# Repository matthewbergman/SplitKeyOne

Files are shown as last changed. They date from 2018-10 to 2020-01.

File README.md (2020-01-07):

# SplitKeyOne
Very simple split keyboard PCB layout and firmware using Cherry MX switches and Teensy3 micro.

### CAD
KiCAD pcb files

TODO:
* Fix the stabalizer mounting holes for vertically mounted keycaps
* Add more mounting holes for rigidity
* Switch to SMT diodes or switches with built in diodes

### SplitKeyOneFirmware
Simple firmware to read the key matrix and send the correct keypress or keyrelease signal. Optionally lights up the LED for each key while it is pressed.

TODO:
* Emulate mouse buttons
* Emulate joystick axis and buttons

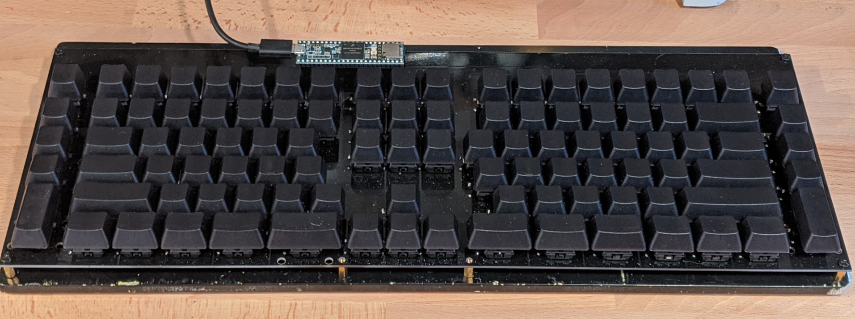
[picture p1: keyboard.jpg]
Keyboard


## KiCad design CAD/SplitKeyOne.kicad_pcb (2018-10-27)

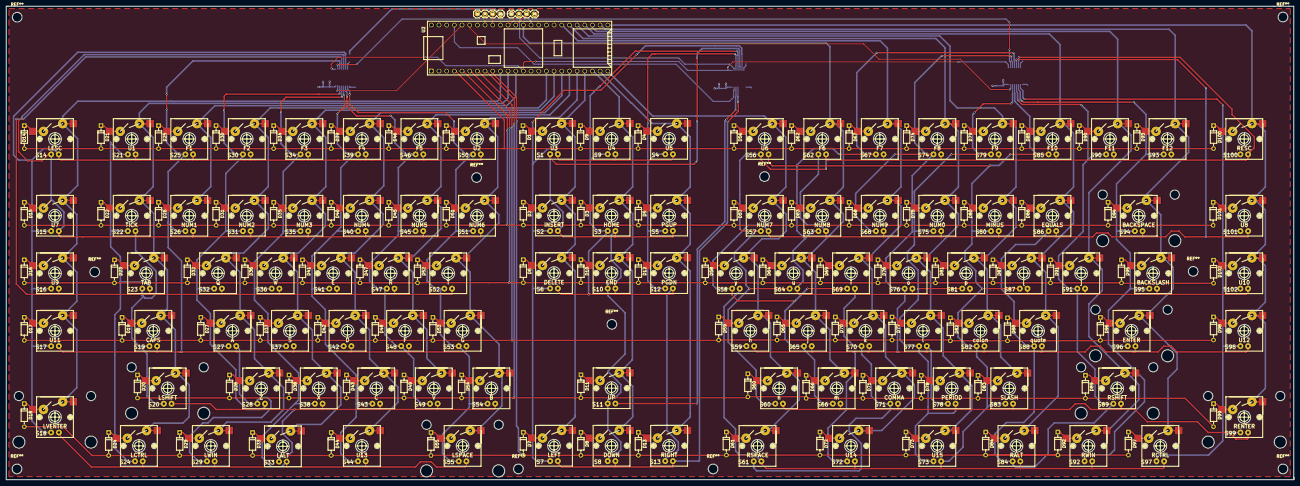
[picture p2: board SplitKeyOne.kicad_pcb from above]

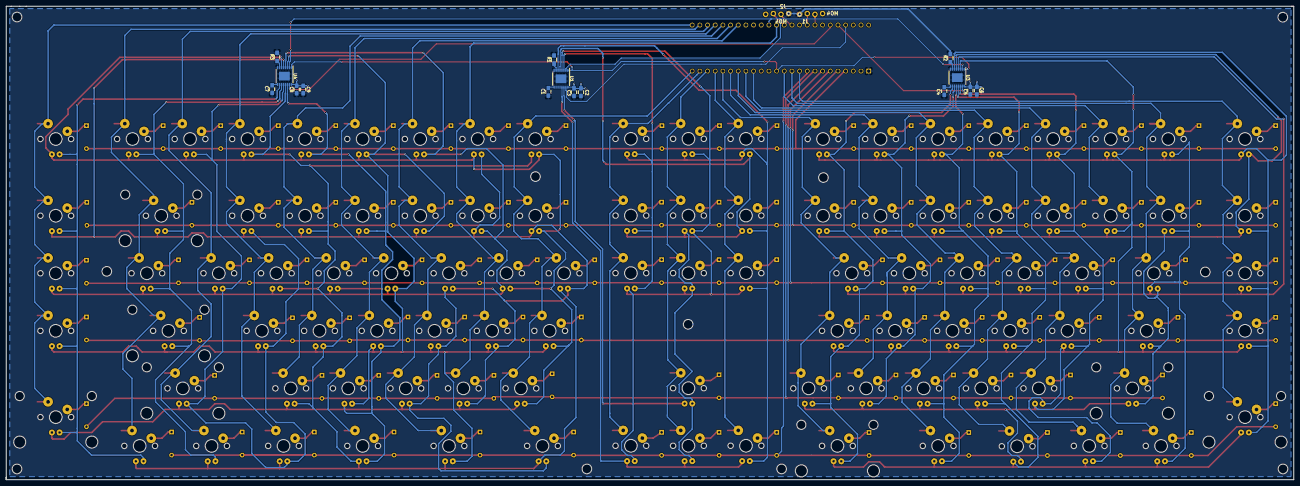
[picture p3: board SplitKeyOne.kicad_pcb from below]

Board: 2 copper layers, 426.2 x 156.7 mm, 222 parts (15 on the bottom side), 169 nets.

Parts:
C1, C4: 27pF; C_0805_HandSoldering
C2, C5, C8: 22uF; C_0805_HandSoldering
C3, C6, C9: 0.1uF; C_0805_HandSoldering
C7: C; C_0805_HandSoldering
D1, D2, D3, D4, D5, D6, D7, D8, D9, D10, D11, D12, D13, D14, D15, D16, D17, D18, D19, D20, D21, D22, D23, D24, D25, D26, D27, D28, D29, D30, D31, D32, D33, D34, D35, D36, D37, D38, D39, D40, D41, D42, D43, D44, D45, D46, D47, D48, D49, D50, D51, D52, D53, D54, D55, D56, D57, D58, D59, D60, D61, D62, D63, D64, D65, D66, D67, D68, D69, D70, D71, D72, D73, D74, D75, D76, D77, D78, D79, D80, D81, D82, D83, D84, D85, D86, D87, D88, D89, D90, D91, D92, D93, D94, D95, D96, D97, D98, D99, D100, D101, D102: D; D_DO-35_SOD27_P7.62mm_Horizontal
J1, J2: M04; SparkFun-1X04_LOCK
R1, R3: 56k; R_0805_HandSoldering
R2: 56K; R_0805_HandSoldering
S1: U3; CHERRY-MX-LED-Socket
S2: INSERT; CHERRY-MX-LED-Socket
S3: HOME; CHERRY-MX-LED-Socket
S4: U5; CHERRY-MX-LED-Socket
S5: PGUP; CHERRY-MX-LED-Socket
S6: DELETE; CHERRY-MX-LED-Socket
S7: LEFT; CHERRY-MX-LED-Socket
S8: DOWN; CHERRY-MX-LED-Socket
S9: U4; CHERRY-MX-LED-Socket
S10: END; CHERRY-MX-LED-Socket
S11: UP; CHERRY-MX-LED-Socket
S12: PGDN; CHERRY-MX-LED-Socket
S13: RIGHT; CHERRY-MX-LED-Socket
S14: LESC; CHERRY-MX-LED-Socket
S15: U7; CHERRY-MX-LED-Socket
S16: U9; CHERRY-MX-LED-Socket
S17: U11; CHERRY-MX-LED-Socket
S18: LVENTER; CHERRY-MX-LED-Socket-2-stabilizer
S19: CAPS; CHERRY-MX-LED-Socket
S20: LSHIFT; CHERRY-MX-LED-Socket-2-stabilizer
S21: U1; CHERRY-MX-LED-Socket
S22: TICK; CHERRY-MX-LED-Socket
S23: TAB; CHERRY-MX-LED-Socket
S24: LCTRL; CHERRY-MX-LED-Socket
S25: F1; CHERRY-MX-LED-Socket
S26: NUM1; CHERRY-MX-LED-Socket
S27: A; CHERRY-MX-LED-Socket
S28: Z; CHERRY-MX-LED-Socket
S29: LWIN; CHERRY-MX-LED-Socket
S30: F2; CHERRY-MX-LED-Socket
S31: NUM2; CHERRY-MX-LED-Socket
S32: Q; CHERRY-MX-LED-Socket
S33: LALT; CHERRY-MX-LED-Socket
S34: F3; CHERRY-MX-LED-Socket
S35: NUM3; CHERRY-MX-LED-Socket
S36: W; CHERRY-MX-LED-Socket
S37: S; CHERRY-MX-LED-Socket
S38: X; CHERRY-MX-LED-Socket
S39: F4; CHERRY-MX-LED-Socket
S40: NUM4; CHERRY-MX-LED-Socket
S41: E; CHERRY-MX-LED-Socket
S42: D; CHERRY-MX-LED-Socket
S43: C; CHERRY-MX-LED-Socket
S44: U13; CHERRY-MX-LED-Socket
S45: NUM5; CHERRY-MX-LED-Socket
S46: F5; CHERRY-MX-LED-Socket
S47: R; CHERRY-MX-LED-Socket
S48: F; CHERRY-MX-LED-Socket
S49: V; CHERRY-MX-LED-Socket
S50: U2; CHERRY-MX-LED-Socket
S51: NUM6; CHERRY-MX-LED-Socket
S52: T; CHERRY-MX-LED-Socket
S53: G; CHERRY-MX-LED-Socket
S54: B; CHERRY-MX-LED-Socket
S55: LSPACE; CHERRY-MX-LED-Socket-2-stabilizer
S56: U6; CHERRY-MX-LED-Socket
S57: NUM7; CHERRY-MX-LED-Socket
S58: y; CHERRY-MX-LED-Socket
S59: h; CHERRY-MX-LED-Socket
S60: n; CHERRY-MX-LED-Socket
S61: RSPACE; CHERRY-MX-LED-Socket
S62: F6; CHERRY-MX-LED-Socket
S63: NUM8; CHERRY-MX-LED-Socket
S64: u; CHERRY-MX-LED-Socket
S65: j; CHERRY-MX-LED-Socket
S66: m; CHERRY-MX-LED-Socket
S67: F7; CHERRY-MX-LED-Socket
S68: NUM9; CHERRY-MX-LED-Socket
S69: i; CHERRY-MX-LED-Socket
S70: k; CHERRY-MX-LED-Socket
S71: COMMA; CHERRY-MX-LED-Socket
S72: U14; CHERRY-MX-LED-Socket
S73: U15; CHERRY-MX-LED-Socket
S74: F8; CHERRY-MX-LED-Socket
S75: NUM0; CHERRY-MX-LED-Socket
S76: o; CHERRY-MX-LED-Socket
S77: l; CHERRY-MX-LED-Socket
S78: PERIOD; CHERRY-MX-LED-Socket
S79: F9; CHERRY-MX-LED-Socket
S80: MINUS; CHERRY-MX-LED-Socket
S81: p; CHERRY-MX-LED-Socket
S82: colon; CHERRY-MX-LED-Socket
S83: SLASH; CHERRY-MX-LED-Socket
S84: RALT; CHERRY-MX-LED-Socket
S85: F10; CHERRY-MX-LED-Socket
S86: EQUALS; CHERRY-MX-LED-Socket
S87: {; CHERRY-MX-LED-Socket
S88: quote; CHERRY-MX-LED-Socket
S89: RSHIFT; CHERRY-MX-LED-Socket-2-stabilizer
S90: F11; CHERRY-MX-LED-Socket
S91: ]; CHERRY-MX-LED-Socket
S92: RWIN; CHERRY-MX-LED-Socket
S93: F12; CHERRY-MX-LED-Socket
S94: BACKSPACE; CHERRY-MX-LED-Socket-2-stabilizer
S95: BACKSLASH; CHERRY-MX-LED-Socket
S96: ENTER; CHERRY-MX-LED-Socket-2-stabilizer
S97: RCTRL; CHERRY-MX-LED-Socket
S98: U12; CHERRY-MX-LED-Socket
S99: RENTER; CHERRY-MX-LED-Socket-2-stabilizer
S100: RESC; CHERRY-MX-LED-Socket
S101: U8; CHERRY-MX-LED-Socket
S102: U10; CHERRY-MX-LED-Socket
U1, U3, U4: MAX6951; TSSOP-16-1EP_4.4x5mm_Pitch0.65mm
U2: Teensy3.6_nopogo; Teensy35_36_nopogo

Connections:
5V: C2.1, C3.1, C5.1, C6.1, C8.1, C9.1, J1.4, J2.4, U1.16, U2.53, U3.16, U4.16
/C9: S1.S2, S2.S2, S6.S2, S7.S2, U2.21
/C10: S3.S2, S8.S2, S9.S2, S10.S2, S11.S2, U2.22
/C11: S4.S2, S5.S2, S12.S2, S13.S2, U2.23
/G15: J2.3, U2.42
/G16: J2.2, U2.43
/LED0: S1.K, S2.A, S4.K, S6.A, S7.A, S9.K, U1.6
/LED1: S1.A, S2.K, S3.K, S5.K, S8.A, S10.A, S11.A, U1.5
/LED2: S3.A, S6.K, S9.A, S10.K, S12.K, S13.A, U1.4
/LED3: S4.A, S5.A, S12.A, U1.3
/LED4: S11.K, U1.14
/LED5: S7.K, S8.K, S13.K, U1.13
/LED_CS1: U1.15, U2.50
/left/LED0: S14.K, S15.A, S16.A, S17.A, S18.A, S21.K, S25.K, S30.K, S34.K, S39.K, S46.K, S50.K, U3.6
/left/LED1: S14.A, S15.K, S19.A, S20.A, S22.K, S23.A, S26.K, S31.K, S35.K, S40.K, S45.K, S51.K, U3.5
/left/LED2: S16.K, S21.A, S22.A, S23.K, S24.A, S32.K, S36.K, S41.K, S47.K, S52.K, U3.4
/left/LED3: S17.K, S19.K, S25.A, S26.A, S27.K, S28.A, S29.A, S37.K, S42.K, S48.K, S53.K, U3.3
/left/LED4: S20.K, S27.A, S28.K, S30.A, S31.A, S32.A, S33.A, S38.K, S43.K, S49.K, S54.K, U3.14
/left/LED5: S18.K, S24.K, S29.K, S33.K, S34.A, S35.A, S36.A, S37.A, S38.A, S44.K, S55.K, U3.13
/left/LED6: S39.A, S40.A, S41.A, S42.A, S43.A, S44.A, U3.12
/left/LED7: S45.A, S46.A, S47.A, S48.A, S49.A, U3.11
/left/LED8: S50.A, S51.A, S52.A, S53.A, S54.A, S55.A, U3.10
/right/LED0: S56.A, S57.A, S59.A, S60.A, S62.K, S64.A, S67.K, S74.K, S79.K, S85.K, S90.K, S93.K, S100.K, U4.6
/right/LED1: S57.K, S58.A, S62.A, S63.K, S65.A, S66.A, S68.K, S69.A, S75.K, S80.K, S86.K, S94.K, S101.K, U4.5
/right/LED2: S61.A, S63.A, S64.K, S67.A, S69.K, S70.A, S71.A, S76.K, S81.K, S87.K, S91.K, S95.K, S102.K, U4.4
/right/LED3: S59.K, S65.K, S68.A, S70.K, S72.A, S74.A, S76.A, S77.K, S78.A, S82.K, S88.K, S96.K, S98.K, U4.3
/right/LED4: S60.K, S66.K, S71.K, S73.A, S75.A, S77.A, S78.K, S79.A, S81.A, S83.K, S89.K, S99.K, U4.14
/right/LED5: S56.K, S58.K, S61.K, S72.K, S73.K, S80.A, S82.A, S83.A, S84.K, S85.A, S87.A, S92.K, S97.K, U4.13
/right/LED6: S84.A, S86.A, S88.A, S89.A, S90.A, S91.A, U4.12
/right/LED7: S92.A, S93.A, S94.A, S95.A, S96.A, U4.11
/right/LED8: S97.A, S98.A, S99.A, S100.A, S101.A, S102.A, U4.10
C1: S14.S2, S15.S2, S16.S2, S17.S2, S18.S2, U2.10
C2: S19.S2, S20.S2, S21.S2, S22.S2, S23.S2, S24.S2, U2.11
C3: S25.S2, S26.S2, U2.12
C4: S27.S2, S28.S2, S29.S2, S30.S2, S31.S2, S32.S2, U2.16
C5: S33.S2, S34.S2, S35.S2, S36.S2, S37.S2, S38.S2, U2.17
C6: S39.S2, S40.S2, S41.S2, S42.S2, S43.S2, S44.S2, U2.18
C7: S45.S2, S46.S2, S47.S2, S48.S2, S49.S2, U2.19
C8: S50.S2, S51.S2, S52.S2, S53.S2, S54.S2, S55.S2, U2.20
C12: S56.S2, S57.S2, S58.S2, S59.S2, S60.S2, S61.S2, U2.24
C13: S62.S2, S63.S2, S64.S2, S65.S2, S66.S2, U2.41
C14: S67.S2, S68.S2, S69.S2, S70.S2, S71.S2, S72.S2, U2.36
C15: S73.S2, S74.S2, S75.S2, S76.S2, S77.S2, S78.S2, U2.35
C16: S79.S2, S80.S2, S81.S2, S82.S2, S83.S2, U2.34
C17: S84.S2, S85.S2, S86.S2, S87.S2, S88.S2, U2.33
C18: S89.S2, S90.S2, S91.S2, S92.S2, U2.32
C19: S93.S2, S94.S2, S95.S2, S96.S2, S97.S2, U2.31
C20: S98.S2, S99.S2, S100.S2, S101.S2, S102.S2, U2.30
GND: C1.2, C2.2, C3.2, C4.2, C5.2, C6.2, C7.2, C8.2, C9.2, J1.1, J2.1, R1.2, R2.2, R3.2, U1.8, U1.17, U2.1, U3.8, U3.17, U4.8, U4.17
LED_CS2: U2.49, U3.15
LED_CS3: U2.48, U4.15
MOSI: U1.1, U2.13, U3.1, U4.1
unnamed: C1.1, U1.9
unnamed: C4.1, U3.9
unnamed: C7.1, U4.9
unnamed: D1.1, S1.S1
unnamed: D2.1, S2.S1
unnamed: D3.1, S3.S1
unnamed: D4.1, S4.S1
unnamed: D5.1, S5.S1
unnamed: D6.1, S6.S1
unnamed: D7.1, S7.S1
unnamed: D8.1, S8.S1
unnamed: D9.1, S9.S1
unnamed: D10.1, S10.S1
unnamed: D11.1, S11.S1
unnamed: D12.1, S12.S1
unnamed: D13.1, S13.S1
unnamed: D14.1, S14.S1
unnamed: D15.1, S15.S1
unnamed: D16.1, S16.S1
unnamed: D17.1, S17.S1
unnamed: D18.1, S18.S1
unnamed: D19.1, S19.S1
unnamed: D20.1, S20.S1
unnamed: D21.1, S21.S1
unnamed: D22.1, S22.S1
unnamed: D23.1, S23.S1
unnamed: D24.1, S24.S1
unnamed: D25.1, S25.S1
unnamed: D26.1, S26.S1
unnamed: D27.1, S27.S1
unnamed: D28.1, S28.S1
unnamed: D29.1, S29.S1
unnamed: D30.1, S30.S1
unnamed: D31.1, S31.S1
unnamed: D32.1, S32.S1
unnamed: D33.1, S33.S1
unnamed: D34.1, S34.S1
unnamed: D35.1, S35.S1
unnamed: D36.1, S36.S1
unnamed: D37.1, S37.S1
unnamed: D38.1, S38.S1
unnamed: D39.1, S39.S1
unnamed: D40.1, S40.S1
unnamed: D41.1, S41.S1
unnamed: D42.1, S42.S1
unnamed: D43.1, S43.S1
unnamed: D44.1, S44.S1
unnamed: D45.1, S45.S1
unnamed: D46.1, S46.S1
unnamed: D47.1, S47.S1
unnamed: D48.1, S48.S1
unnamed: D49.1, S49.S1
unnamed: D50.1, S50.S1
unnamed: D51.1, S51.S1
unnamed: D52.1, S52.S1
unnamed: D53.1, S53.S1
unnamed: D54.1, S54.S1
unnamed: D55.1, S55.S1
unnamed: D56.1, S56.S1
unnamed: D57.1, S57.S1
unnamed: D58.1, S58.S1
unnamed: D59.1, S59.S1
unnamed: D60.1, S60.S1
unnamed: D61.1, S61.S1
unnamed: D62.1, S62.S1
unnamed: D63.1, S63.S1
unnamed: D64.1, S64.S1
unnamed: D65.1, S65.S1
unnamed: D66.1, S66.S1
unnamed: D67.1, S67.S1
unnamed: D68.1, S68.S1
unnamed: D69.1, S69.S1
unnamed: D70.1, S70.S1
unnamed: D71.1, S71.S1
unnamed: D72.1, S72.S1
unnamed: D73.1, S73.S1
unnamed: D74.1, S74.S1
unnamed: D75.1, S75.S1
unnamed: D76.1, S76.S1
unnamed: D77.1, S77.S1
unnamed: D78.1, S78.S1
unnamed: D79.1, S79.S1
unnamed: D80.1, S80.S1
unnamed: D81.1, S81.S1
unnamed: D82.1, S82.S1
unnamed: D83.1, S83.S1
unnamed: D84.1, S84.S1
unnamed: D85.1, S85.S1
unnamed: D86.1, S86.S1
unnamed: D87.1, S87.S1
unnamed: D88.1, S88.S1
unnamed: D89.1, S89.S1
unnamed: D90.1, S90.S1
unnamed: D91.1, S91.S1
unnamed: D92.1, S92.S1
unnamed: D93.1, S93.S1
unnamed: D94.1, S94.S1
unnamed: D95.1, S95.S1
unnamed: D96.1, S96.S1
unnamed: D97.1, S97.S1
unnamed: D98.1, S98.S1
unnamed: D99.1, S99.S1
unnamed: D100.1, S100.S1
unnamed: D101.1, S101.S1
unnamed: D102.1, S102.S1
unnamed: R1.1, U1.7
unnamed: R2.1, U3.7
unnamed: R3.1, U4.7
R1: D1.2, D4.2, D9.2, D14.2, D21.2, D25.2, D30.2, D34.2, D39.2, D46.2, D50.2, D56.2, D62.2, D67.2, D74.2, D79.2, D85.2, D90.2, D93.2, D100.2, U2.4
R2: D2.2, D3.2, D5.2, D15.2, D22.2, D26.2, D31.2, D35.2, D40.2, D45.2, D51.2, D57.2, D63.2, D68.2, D75.2, D80.2, D86.2, D94.2, D101.2, U2.5
R3: D6.2, D10.2, D12.2, D16.2, D23.2, D32.2, D36.2, D41.2, D47.2, D52.2, D58.2, D64.2, D69.2, D76.2, D81.2, D87.2, D91.2, D95.2, D102.2, U2.6
R4: D17.2, D19.2, D27.2, D37.2, D42.2, D48.2, D53.2, D59.2, D65.2, D70.2, D77.2, D82.2, D88.2, D96.2, D98.2, U2.7
R5: D11.2, D20.2, D28.2, D38.2, D43.2, D49.2, D54.2, D60.2, D66.2, D71.2, D78.2, D83.2, D89.2, D99.2, U2.8
R6: D7.2, D8.2, D13.2, D18.2, D24.2, D29.2, D33.2, D44.2, D55.2, D61.2, D72.2, D73.2, D84.2, D92.2, D97.2, U2.9
SCK: U1.2, U2.40, U3.2, U4.2
SCL: J1.3, U2.46
SDA: J1.2, U2.45

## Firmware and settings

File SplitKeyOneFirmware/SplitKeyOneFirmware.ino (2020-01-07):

/**
 * @file SplitKeyOneFirmware.ino
 *
 * @brief Simple keyboard firmware for the Teensy 3 micro for use
 * as a starting point for more complex keyboard projects.
 *
 * @author Matt Bergman
 * 
 * Copyright (C) 2018
 * 
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
 * You should have received a copy of the GNU General Public License
 * along with this program.  If not, see <http://www.gnu.org/licenses/>.
 */

#include <SPI.h>

//#define LEDS
//#define DEBUG

// SPI select pins for LED drivers
const int LED_SS0_pin = 22;
const int LED_SS1_pin = 23;
const int LED_SS2_pin = 21;

// IO pins for rows and columns on keyboard matrix
byte rows[] = {2,3,4,5,6,7};
byte cols[] = {8,9,10,24,25,26,27,28,29,30,31,32,14,39,38,37,36,35,34,33};
const int row_count = sizeof(rows)/sizeof(rows[0]);
const int col_count = sizeof(cols)/sizeof(cols[0]);

// This is the main key map
int keymap[row_count][col_count] = {
// 0               1                 2                3               4               5               6               7               8                    9                    10                   11              12              13              14              15              16                    17                      18                     19
  {KEY_ESC        ,KEY_SCROLL_LOCK  ,KEY_F1          ,KEY_F2         ,KEY_F3         ,KEY_F4         ,KEY_F5         ,KEY_MEDIA_PREV_TRACK,KEY_MEDIA_VOLUME_DEC,KEY_MEDIA_VOLUME_INC,KEY_MEDIA_PLAY_PAUSE,KEY_MEDIA_NEXT_TRACK,KEY_F6         ,KEY_F7         ,KEY_F8         ,KEY_F9         ,KEY_F10              ,KEY_F11                ,KEY_F12               ,KEY_ESC        },
  {KEY_SCROLL_LOCK,KEY_TILDE        ,KEY_1           ,KEY_2          ,KEY_3          ,KEY_4          ,KEY_5          ,KEY_6          ,KEY_INSERT          ,KEY_HOME            ,KEY_PAGE_UP         ,KEY_7          ,KEY_8          ,KEY_9          ,KEY_0          ,KEY_MINUS      ,KEY_EQUAL            ,KEY_SCROLL_LOCK        ,KEY_BACKSPACE         ,KEY_SCROLL_LOCK},
  {KEY_SCROLL_LOCK,KEY_TAB          ,KEY_SCROLL_LOCK ,KEY_Q          ,KEY_W          ,KEY_E          ,KEY_R          ,KEY_T          ,KEY_DELETE          ,KEY_END             ,KEY_PAGE_DOWN       ,KEY_Y          ,KEY_U          ,KEY_I          ,KEY_O          ,KEY_P          ,KEY_LEFT_BRACE       ,KEY_RIGHT_BRACE        ,KEY_BACKSLASH         ,KEY_SCROLL_LOCK},
  {KEY_SCROLL_LOCK,KEY_CAPS_LOCK    ,KEY_SCROLL_LOCK ,KEY_A          ,KEY_S          ,KEY_D          ,KEY_F          ,KEY_G          ,KEY_SCROLL_LOCK     ,KEY_SCROLL_LOCK     ,KEY_SCROLL_LOCK     ,KEY_H          ,KEY_J          ,KEY_K          ,KEY_L          ,KEY_SEMICOLON  ,KEY_QUOTE            ,KEY_SCROLL_LOCK        ,KEY_ENTER             ,KEY_SCROLL_LOCK},
  {KEY_SCROLL_LOCK,MODIFIERKEY_SHIFT,KEY_SCROLL_LOCK ,KEY_Z          ,KEY_X          ,KEY_C          ,KEY_V          ,KEY_B          ,KEY_SCROLL_LOCK     ,KEY_UP              ,KEY_SCROLL_LOCK     ,KEY_N          ,KEY_M          ,KEY_COMMA      ,KEY_PERIOD     ,KEY_SLASH      ,KEY_SCROLL_LOCK      ,MODIFIERKEY_RIGHT_SHIFT,KEY_SCROLL_LOCK       ,KEY_ENTER      },
  {KEY_ENTER      ,MODIFIERKEY_CTRL ,KEY_SCROLL_LOCK,MODIFIERKEY_GUI,MODIFIERKEY_ALT,KEY_SCROLL_LOCK,KEY_SCROLL_LOCK,KEY_SPACE      ,KEY_LEFT            ,KEY_DOWN            ,KEY_RIGHT           ,KEY_SPACE      ,KEY_SCROLL_LOCK,KEY_SCROLL_LOCK,KEY_SCROLL_LOCK,KEY_SCROLL_LOCK,MODIFIERKEY_RIGHT_ALT,MODIFIERKEY_RIGHT_GUI  ,MODIFIERKEY_RIGHT_CTRL,KEY_SCROLL_LOCK},
};

// D7 - dp
// D6 - a
// D5 - b
// D4 - c
// D3 - d 
// D2 - e
// D1 - f 
// D0 - g
// digit: dp-g
int leddmap[row_count][col_count] = {
  {0,0,0,0,0,0,0,0,7,0,1,7,7,0,1,2,3,4,5,6},
  {0,0,0,0,0,0,0,0,7,0,1,7,0,1,2,3,4,4,5,6},
  {0,0,0,0,0,0,0,0,7,0,1,0,7,0,1,2,3,4,5,6},
  {0,0,0,0,0,0,0,0,0,0,0,7,0,1,2,3,4,5,5,6},
  {0,0,0,0,0,0,0,0,0,0,0,7,0,1,2,3,3,4,5,6},
  {0,0,0,0,0,0,0,0,7,0,1,1,1,2,3,4,4,5,6,6},
};
// address: (row)
int ledamap[row_count][col_count] = {
  {0,0,0,0,0,0,0,0,0,0,0,5,0,0,0,0,0,0,0,0},
  {1,1,1,1,1,1,1,1,1,1,1,1,1,1,1,1,1,1,1,1},
  {2,2,2,2,2,2,2,2,2,2,2,5,2,2,2,2,2,2,2,2},
  {3,3,3,3,3,3,3,3,3,3,3,3,3,3,3,3,3,3,3,3},
  {4,4,4,4,4,4,4,4,4,4,4,4,4,4,4,4,4,4,4,4},
  {5,5,5,5,5,5,5,5,5,5,5,5,5,5,5,5,5,5,5,5},
};
// chip: 0,1,2
int ledcmap[row_count][col_count] = {
  {0,0,0,0,0,0,0,0,1,1,1,2,2,2,2,2,2,2,2,2},
  {0,0,0,0,0,0,0,0,1,1,1,2,2,2,2,2,2,2,2,2},
  {0,0,0,0,0,0,0,0,1,1,1,2,2,2,2,2,2,2,2,2},
  {0,0,0,0,0,0,0,0,1,1,1,2,2,2,2,2,2,2,2,2},
  {0,0,0,0,0,0,0,0,1,1,1,2,2,2,2,2,2,2,2,2},
  {0,0,0,0,0,0,0,0,1,1,1,2,2,2,2,2,2,2,2,2},
};

byte keystate[col_count][row_count];
byte ledstate[3][8] = {
  {0,0,0,0,0,0,0,0},
  {0,0,0,0,0,0,0,0},
  {0,0,0,0,0,0,0,0},
};

void setup() 
{
  #ifdef DEBUG
  Serial.begin(115200);
  #endif

  for(int x=0; x<row_count; x++)
    pinMode(rows[x], INPUT_PULLUP);
  for (int x=0; x<col_count; x++)
    pinMode(cols[x], OUTPUT);

  #ifdef LEDS
  pinMode(LED_SS0_pin, OUTPUT);
  pinMode(LED_SS1_pin, OUTPUT);
  pinMode(LED_SS2_pin, OUTPUT);
  SPI.begin();

  delay(20);
  digitalWrite(LED_SS1_pin,LOW);
  SPI.transfer(0x04);
  SPI.transfer(0x01); // normal mode
  digitalWrite(LED_SS1_pin,HIGH);
  delay(20);
  digitalWrite(LED_SS1_pin,LOW);
  SPI.transfer(0x02);
  SPI.transfer(0x02); // intensity
  digitalWrite(LED_SS1_pin,HIGH);
  //delay(20);
  //digitalWrite(LED_SS1_pin,LOW);
  //SPI.transfer(0x07);
  //SPI.transfer(0x01);
  //digitalWrite(LED_SS1_pin,HIGH); 

  delay(20);
  digitalWrite(LED_SS2_pin,LOW);
  SPI.transfer(0x04);
  SPI.transfer(0x01); // normal mode
  digitalWrite(LED_SS2_pin,HIGH);
  delay(20);
  digitalWrite(LED_SS2_pin,LOW);
  SPI.transfer(0x02);
  SPI.transfer(0x02); // intensity
  digitalWrite(LED_SS2_pin,HIGH);
  //delay(20);
  //digitalWrite(LED_SS2_pin,LOW);
  //SPI.transfer(0x07);
  //SPI.transfer(0x01);
  //digitalWrite(LED_SS2_pin,HIGH); 

  delay(20);
  digitalWrite(LED_SS0_pin,LOW);
  SPI.transfer(0x04);
  SPI.transfer(0x01); // normal mode
  digitalWrite(LED_SS0_pin,HIGH);
  delay(20);
  digitalWrite(LED_SS0_pin,LOW);
  SPI.transfer(0x02);
  SPI.transfer(0x02); // intensity
  digitalWrite(LED_SS0_pin,HIGH);
  //delay(20);
  //digitalWrite(LED_SS0_pin,LOW);
  //SPI.transfer(0x07);
  //SPI.transfer(0x01);
  //digitalWrite(LED_SS0_pin,HIGH); 
  #endif
}

void update_leds(byte row, byte col, byte state)
{
  #ifndef LEDS
  return;
  #endif
  
  byte chip = ledcmap[row][col];
  byte addr = ledamap[row][col];
  byte digit = leddmap[row][col];
  byte ss = 0;
  if (chip == 0)
    ss = LED_SS0_pin;
  else if (chip == 1)
    ss = LED_SS1_pin;
  else if (chip == 2)
    ss = LED_SS2_pin;

  byte curval = ledstate[chip][addr];
  if (state == 1)
    curval |= (1 << digit);
  else
    curval &= ~(1 << digit);
  ledstate[chip][addr] = curval;

  #ifdef DEBUG
  Serial.print("Addr ");
  Serial.print(addr);
  Serial.print(" val ");
  Serial.println(curval);
  #endif
  
  digitalWrite(ss,LOW);
  SPI.transfer(0x20 + addr);
  SPI.transfer(curval);
  digitalWrite(ss,HIGH); 
}
 
void read_matrix()
{
  byte column;
  byte row;
  byte new_val;
    
  for (byte col_index=0; col_index < col_count; col_index++) 
  {
    column = cols[col_index];

    // Scan a column
    digitalWrite(column, LOW);
 
    for (byte row_index=0; row_index < row_count; row_index++) 
    {
      // Read the rows
      row = rows[row_index];
      new_val = digitalRead(row);
      delayMicroseconds(10);
      new_val = digitalRead(row);
      delayMicroseconds(10);
      if (keystate[col_index][row_index] != new_val)
      {
        keystate[col_index][row_index] = new_val;
        
        #ifdef DEBUG
        Serial.print(new_val);Serial.print(" ");Serial.print(row_index);Serial.print('x');Serial.println(col_index);
        #endif
        
        if (new_val == 0)
        {
          /*
          if (row_index == 1 && col_index == 10)
            Mouse.press(MOUSE_LEFT);
          else if (row_index == 2 && col_index == 10)
            Mouse.press(MOUSE_RIGHT);
          else
          */
            Keyboard.press(keymap[row_index][col_index]);
            update_leds(row_index,col_index,1);
        }
        else
        {
          /*
          if (row_index == 1 && col_index == 10)
            Mouse.release(MOUSE_LEFT);
          else if (row_index == 2 && col_index == 10)
            Mouse.release(MOUSE_RIGHT);
          else
          */
            Keyboard.release(keymap[row_index][col_index]);
            update_leds(row_index,col_index,0);
        }
      }
    }
    digitalWrite(column, HIGH);
  }
  delay(1);
}
 
void loop() 
{
  read_matrix();
}

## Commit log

2018-10-15 Initial commit.
    [SplitKeyOne.kicad_pcb, SplitKeyOne.sch, left.sch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]
2018-10-15 Rough layout of right side.
    [SplitKeyOne.kicad_pcb, right.sch]
2018-10-18 Hopefully final layout of keys.
    [SplitKeyOne.kicad_pcb]
2018-10-18 Final key placement.
    [SplitKeyOne.kicad_pcb]
2018-10-19 More routing.
    [SplitKeyOne.kicad_pcb, SplitKeyOne.sch, left.sch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]
2018-10-19 Board routed.
    [SplitKeyOne.kicad_pcb, SplitKeyOne.sch, left.sch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]
2018-10-20 Mounting holes.
    [SplitKeyOne.kicad_pcb, SplitKeyOne.sch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]
2018-10-27 Making outlines for routing the plate.
    [SplitKeyOne.kicad_pcb, SplitKeyOne.sch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]
2018-10-27 Moving KiCAD to CAD folder.
    [SplitKeyOne.kicad_pcb, SplitKeyOne.sch, left.sch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]
2018-11-02 LED code

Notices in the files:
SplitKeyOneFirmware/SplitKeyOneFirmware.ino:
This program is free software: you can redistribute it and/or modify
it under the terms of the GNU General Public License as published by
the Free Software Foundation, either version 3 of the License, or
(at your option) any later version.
